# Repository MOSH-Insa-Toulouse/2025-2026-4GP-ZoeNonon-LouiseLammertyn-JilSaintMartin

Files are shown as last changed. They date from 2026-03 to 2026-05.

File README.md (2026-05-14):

# 2025-2026-4GP-ZoeNonon-LouiseLammertyn-JilSaintMartin
### Introduction

Dans le cadre de la formation en Génie Physique de l'INSA Toulouse, les étudiants de 4ème année doivent réaliser un capteur low-tech à base de graphite et en faire une analyse critique. Le but final étant de répondre à la question suivante:  

<p align="center">
  <strong>Un capteur graphite low-tech peut-il remplacer un flexeur commercial ?</strong>
</p>

Ce capteur graphitte se base sur les travaux de:

  - [1]	K.-H. Müller, J. Herrmann, B. Raguse, G. Baxter, and T. Reda, “Percolation model for electron conduction in films of metal nanoparticles linked by organic molecules,” Phys. Rev. B, vol. 66, no. 7, p. 075417, Aug. 2002, doi: 10.1103/PhysRevB.66.075417.
  
  - [2]	C.-W. Lin, Z. Zhao, J. Kim, and J. Huang, “Pencil Drawn Strain Gauges and Chemiresistors on Paper,” Sci. Rep., vol. 4, no. 1, p. 3812, Jan. 2014, doi: 10.1038/srep03812.
  
  - [3]	K.-H. Müller, J. Herrmann, G. Wei, B. Raguse, and L. Wieczorek, “Electron transport in nanoparticle assemblies,” in 2010 International Conference on Nanoscience and Nanotechnology, Feb. 2010, pp. 316–318. doi: 10.1109/ICONN.2010.6045236.

### Description du projet 
Le capteur de contrainte en graphite repose sur un réseau conducteur de particules de graphite déposées sur un substrat en papier.
Lorsque l'on trace un trait au crayon sur du papier, les particules de graphite adhèrent aux fibres, formant ainsi un mince film conducteur.
Ce film se comporte comme un système granulaire désordonné où la conduction électrique s'effectue par le biais des contacts entre les particules de graphite.
La déformation mécanique affecte ce réseau :
  - Sous contrainte de traction, la distance entre les particules augmente, ce qui réduit les contacts électriques et augmente la résistance.
  - Sous contrainte de compression, les particules sont rapprochées, ce qui améliore la connectivité et diminue la résistance.

La réponse du capteur est donc régie par les variations du réseau et les effets de tunnel entre particules voisines.
En raison de sa structure, le capteur est très sensible aux petites déformations, mais il est également influencé par des paramètres de fabrication tels que la densité du graphite, la dureté du crayon et les conditions environnementales (humidité, température).

<p align="center">
échelle_crayon
</p>
<p align="center">
  <em>Echelle évaluant la dureté de différentes mines de crayons</em>
</p>

**La variation de résistance qui en résulte peut être mesurée à l'aide d'un circuit à transimpédance, afin d'obtenir un signal analogique.**

Ce projet se divise en plusieurs étapes décrites ci-dessous. 

<p align="center">
Logo en noir
</p>
<p align="center">
  <em>Logo du capteur graphite "GraphiFlop"</em>
</p>

### Livrables
Pour valider ce projet nous devons proposer: 
- Un circuit imprimé (PCB) pour créer les circuits électroniques reliant nos composants
- Un code arduino qui permet de contrôler un ARDUINO afin de mesurer la résistance du capteur, faire nos tests et contrôler des éléments tels que le bluetooth, l'écran ou l'encodeur rotatoire
- Une datasheet présentant les caractéristiques du capteur graphite fabriqué
- Une application ANDROID permettant de recevoir les données par bluetooth et les afficher sur un graphique

### Matériel
Afin de réaliser ce capteur, nous utilisons le matériel suivant: 

- Une carte Arduino UNO
- Un écran OLED (I2C)
- Un potentiomètre numérique MCP41050
- Un encodeur rotatoire
- Un capteur de déformation en papier low tech
- Un module bluetooth

Pour réaliser l'amplificateur transimpédance, nous avons utilisé: 

- Un amplificateur opérationnel LTC1050
- Deux condensateurs de 100nF
- Un condensateur de 1µF
- Deux résistances de 100kΩ
- Deux résistances de 1kΩ
- Une résistance de 10kΩ

### LTspice
La première étape de se projet est de simuler le circuit d'amplification transimpédance du capteur sur LTspice. 
Le  montage est un amplificateur à transimpédance (TIA) basé sur l’AOP LTC1050.

Le principe du montage est de convertir le courant traversant le capteur en une tension exploitable. L’amplificateur opérationnel, configuré en transimpédance, permet d’obtenir une tension de sortie proportionnelle à la valeur de la résistance.

Un filtre passe-bas est ajouté en sortie afin de réduire le bruit et de fournir un signal stable, compatible avec une entrée analogique.

Dans la suite du projet, R2 sera remplacée par un potentiomètre numérique, afin de permettre la calibration de l’Arduino sur une plage de tension comprise entre 0 et 5 V.

<p align="center">
capteur
</p>
<p align="center">
  <em>Circuit d'amplification transimpédance sur LTspice</em>
</p>

Pour consulter les différents fichiers, aller à [2.LTSpice](https://github.com/MOSH-Insa-Toulouse/2025-2026-4GP-ZoeNonon-LouiseLammertyn-JilSaintMartin/tree/main/2.LTSpice)

### Kicad

Une fois la simulation validée sur LTspice, l'étape suivante consiste à transformer le schéma théorique en un objet physique fonctionnel : le Circuit Imprimé (PCB). 
Pour ce faire, nous utilisons la suite logicielle KiCad.

Cette phase de conception se décompose en trois étapes majeures :

**Saisie schématique et empreinte**

La première étape consiste à reproduire le circuit de l’amplificateur transimpédance.
- Intégration des composants: Nous y plaçons l'AOP LTC1050, les composants passifs (résistances, condensateurs) et les connecteurs nécessaires à l'Arduino Uno, l'écran OLED et l'encodeur rotatif.
- Association des empreintes: Chaque symbole schématique est lié à une empreinte physique réelle. Cette étape est cruciale pour assurer que les composants pourront être soudés correctement sur le cricuit final.

<p align="center">
 shm
</p>
<p align="center">
  <em>Visualisation de la schématique du montage sur KiCad</em>
</p>

**Routage et placement**

Le passage au routage permet de définir la disposition physique des éléments sur la carte de cuivre.
- Placement des composants et routages: Nous avons disposé les composants afin de pouvoir router par la suite le plus efficacement possible, sans que les composants et les pistes ne se superposent.
- Plan de masse: Un plan de masse a été intégré pour stabiliser les potentiels et réduire le bruit sur le circuit analogique.

<p align="center">
pcb  
</p>
<p align="center">
  <em>Visualisation du routage du montage sur KiCad</em>
</p>

**Visualisation 3D et vérification**

Enfin, KiCad permet une modélisation 3D du projet. Cet outil nous a permis de:
- Vérifier l'encombrement mécanique des composants.
- Valider la cohérence globale avant la fabrication du PCB.

<p align="center">
  
</p>
<p align="center">
  <em>Visualisation 3D du montage global sur KiCad</em>
</p>

Pour consulter les différents fichiers, aller à [3.KiCad](https://github.com/MOSH-Insa-Toulouse/2025-2026-4GP-ZoeNonon-LouiseLammertyn-JilSaintMartin/tree/main/3.KiCad)

### Fabrication PCB et soudage

<p align="center">
  
</p>
<p align="center">
  <em>Fichier généré par KiCad pour l'impression du PCB</em>
</p>

Une fois le routage validé sous KiCad et le fichier de perçage généré, nous avons pu imprimer notre circuit électronique (merci Cathy <3). Ensuite, nous avons percé et soudé le montage complet. Avant de passer au code Arduino, nous avons vérifié que tout fonctionnait bien à l'aide d'un multimètre, en effectuant les étapes suivantes:
- Vérification que chaque piste relie bien les bons points du schéma.
- Absence totale de court-circuit entre le 5V et le GND.

<p align="center">
  Face_arrière_PCB
</p>
<p align="center">
  <em>Face arrière du PCB</em>
</p>

### Arduino
Il a ensuite été nécessaire de réaliser un code arduino afin de pouvoir contrôler la carte. Ce code permet notamment d'effectuer les mesures sur le capteur graphite et de contrôler les différents composants tels que le module bluetooth, l'écran OLED et l'encodeur rotatoire. 

**Mesure**

La première partie du code est dédiée à la mesure de la tension aux bornes du capteur. A l'aide d'une fonction, la tension mesurée permet de déduire la résistance du capteur. 

Une fonction de calibration a aussi été créee afin de calibrer la tension aux bornes du capteur. Comme l'arduino UNO permet de délivrer une tension entre 0V et 5V, il est intéressant de régler le potentiomètre numérique afin que la tension aux bornes du capteur lorsque le capteur n'est pas tordu, soit de 2,5V. Ce potentiomètre numérique remplace dans le montage électronique la résistance R2.

Notre montage permet aussi d'utiliser un flexor commercial. Pour cela, une fonction au sein du code permet de mesurer la tension différement et d'en déduire la résistance. La calibration n'est cependant pas nécessaire sur ce capteur. 

<p align="center">
  Flexor
</p>
<p align="center">
  <em>Flexor commercial</em>
</p>

La lecture de tension aux bornes du capteur graphite ou du flexor commercial s'effectue toutes les 100ms. 

**Composants pour l'utilisateur**
<p align="center">
  Schéma_composants
</p>
<p align="center">
  <em>Schéma des différents composants</em>
</p>

Le reste du code permet de gérer le reste des composants. Une fonction permet de gérer l'affichage sur l'écran OLED. Sur cet écran, l'affichage d'un menu permet d'intéragir avec l'utilisateur. Une fonction gère l'encodeur rotatoire qui permet à l'utilisateur de se déplacer sur le menu. Enfin, une dernière fonction permet d'envoyer les données mesurées à l'aide du module bluetooth sur un téléphone connecté. 

<p align="center">
  Menu
</p>
<p align="center">
  <em>Menu affiché sur l'écran OLED</em>
</p>

Pour consulter les différents fichiers, aller à [4.Arduino](https://github.com/MOSH-Insa-Toulouse/2025-2026-4GP-ZoeNonon-LouiseLammertyn-JilSaintMartin/tree/main/4.Arduino)

### Application
A l'aide du site internet "MIT App Inventor", nous avons pu créer une interface pour téléphone ANDROID sur laquelle l'arduino UNO peut communiquer des données par bluetooth. Le code de cette application se base sur l'empilage de blocs de code. 

Le code traite d'abord la communication avec le module bluetooth de l'arduino en s'assurant que les données reçues sont bien des valeurs numériques positives. Une fois les données réceptionnées, les données sont affichées sur un graphique qui se met à jour en continu. 

L'application permet par ailleurs d'afficher le mode de mesure en cours (mesure de tension ou de résistance) ainsi que le capteur utilisé. 

<p align="center">
  interface_app
</p>
<p align="center">
  <em>Interface de l'application GraphiFlop</em>
</p>

Pour consulter les différents fichiers, aller à [5.Application](https://github.com/MOSH-Insa-Toulouse/2025-2026-4GP-ZoeNonon-LouiseLammertyn-JilSaintMartin/tree/main/5.Application)

### Banc de tests
Pour cette partie, nous avons utilisé un banc de test conçu par les groupes précédents.
<p align="center">
  banc_test_sans_fond
</p>
<p align="center">
  <em>Banc de test</em>
</p>

Afin de vérifier les résultats obtenus, nous avons tracé la variation relative de la résistance du capteur en fonction de la déformation mécanique. La résistance relative est mesurée pour chaque courbure du banc de test.
La déformation peut être calculée à partir de la géométrie du dispositif selon la relation suivante :

<p align="center">
deformation
</p>

Ensuite, à l’aide du code arduino, nous avons mesuré la résistance du capteur pour quatre types de crayons différents. Une mesure de référence à plat a d’abord été réalisée, puis des mesures ont été effectuées pour différentes courbures du banc de test, en compression et en tension.
La résistance relative est définie par :

 <p align="center">
Rrelative
</p>

Pour consulter les différents fichiers, aller à [6.Banc de tests](https://github.com/MOSH-Insa-Toulouse/2025-2026-4GP-ZoeNonon-LouiseLammertyn-JilSaintMartin/tree/main/6.Banc%20de%20tests)
### Résulats
Nous avons obtenu les courbes suivantes :

<p align="center">
Résultat_compression 
resultat_flexion
</p>

On observe que les résultats obtenus en flexion présentent une relation globalement linéaire entre la déformation et la variation de résistance. Le capteur est donc particulièrement adapté à la mesure de flexion. Cependant la durée de vie du capteur est courte les valeurs sont tres vraibale lorsque que celui ci a deja été pliée. 
On retrouve bien les résultats attendus concernant la sensibilité du capteur en fonction du grade du crayon. Les crayons "tendres" (ex : 6B, à forte concentration en graphite) présentent une sensibilité plus faible que les crayons plus "durs" (ex : HB). 

Cela s’explique par la structure du réseau conducteur : une plus forte densité de graphite rend le chemin de conduction plus stable, ce qui réduit l’amplitude relative des variations de résistance lors des déformations.
En revanche, les résultats en compression sont moins concluants. Bien que les courbes restent globalement affines, la variation de résistance n’est pas entièrement exploitable : le signal tend à revenir vers la résistance au repos lorsque le capteur est courbé.

Ce comportement peut s’expliquer par un phénomène mécanique : en compression, la couche de graphite entre en contact avec le banc de test, entraînant une perte de matière  et une modification irréversible du réseau conducteur.

Enfin, nous n’avons pas réussi à obtenir de mesures exploitables avec les crayons H et 2H, car le signal électrique généré était trop faible pour être détecté par le système de mesure.

Pour consulter les différents fichiers, aller à [7.Datasheet](https://github.com/MOSH-Insa-Toulouse/2025-2026-4GP-ZoeNonon-LouiseLammertyn-JilSaintMartin/tree/main/7.Datasheet)

### Erreur rencontré
Au cours de ce projet, de nombreuse erreurs ont été rencontrées, que nous détaillons ci-dessous. 

Les premiers problèmes rencontrés sont liés à une erreur de routage sur KiCad. En effet, nous avons vite remarqué que certains composants n'étaient pas reliés au bonnes pins de l'arduino comme par exemple le potentiomètre numérique. Nous avons aussi oublié d'ajouter sur le PCB initial des broches afin de connecter le flexor commercial ou bien une capacité associée à l'encodeur rotatoire. Nous avons cependant pu remédier à ces erreurs en ressoudant avec des fils certaines pistes du PCB (encore merci Cathy :)).

<p align="center">
  Face_arrière_PCB_avec_fils_sans_fond
</p>
<p align="center">
  <em>Face arrière du PCB (après réparation)</em>
</p>

Nous avons aussi rencontré des problèmes quant aux codes écrits lors de ce projet. En effet, nous avons fait face à des problèmes de RAM de l'écran OLED. Nous avons pu cependant régler ce problème. Par ailleurs, nous avons aussi eu des difficultés face à la fonction de calibration qui ne fonctionne pas toujours ou bien face à certaines boucles de l'application ANDROID qui ne sont pas toujours lues. Nous n'avons malheureusement pas pu remédier à ces problèmes. 

Enfin, nous avons rencontré des difficultés quant au capteur en lui-même. Le capteur graphite a, comme expliqué précédemment, une durée de vie assez courte ce qui rend difficile certaines mesures.

### Conclusion
Ce capteur est fiable comme le montre les courbes réalisées. Il permet d'effectuer des mesurer tant en flexion qu'en compression (ce qui n'est pas le cas pour un flexor commercial) avec une sensibilité certaine. 
Un avantage considérable du capteur graphite est son prix très bas en comparaison d'un capteur commercial. 

Cependant, la durée de vie du capteur est courte ce qui le rend peut réutilisable. 

Pour conclure, ce capteur graphite est commercialisable à condition de pouvoir augmenter sa durée de vie. On pourrait par exemple proposer l'ajout d'une couche de protection sur le capteur afin d'éviter d'enlever du graphite ainsi que d'utiliser un papier moins fragile. 

<p align="center">
  <strong>GraphiFlop c'est validé! 😎👍</strong>
</p>

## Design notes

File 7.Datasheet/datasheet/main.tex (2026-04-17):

\documentclass[a4paper,12pt,oneside,pdflatex,italian,final,twocolumn]{article}

\usepackage[utf8]{inputenc}
\usepackage{parallel}
\usepackage{siunitx}
\usepackage{booktabs}
\usepackage{fancyhdr}

\usepackage[export]{adjustbox}
\usepackage[margin=0.5in]{geometry}
\addtolength{\topmargin}{0in}

\usepackage{libertine}
\renewcommand*\familydefault{\sfdefault}  %% Only if the base font of the document is to be sans serif
\usepackage[T1]{fontenc}

\title{Graphiflop00001}
\author{Nonon Zoé, Lammertyn Louise, Saint-Martin Jil }
\date{April 2019}

\begin{document}

\pagestyle{fancy}

\lhead{insa toulouse}
\chead {\today}
\rhead{Projet capteur}

\onecolumn

\begin{figure}
\begin{minipage}{0.47\textwidth}
\centering
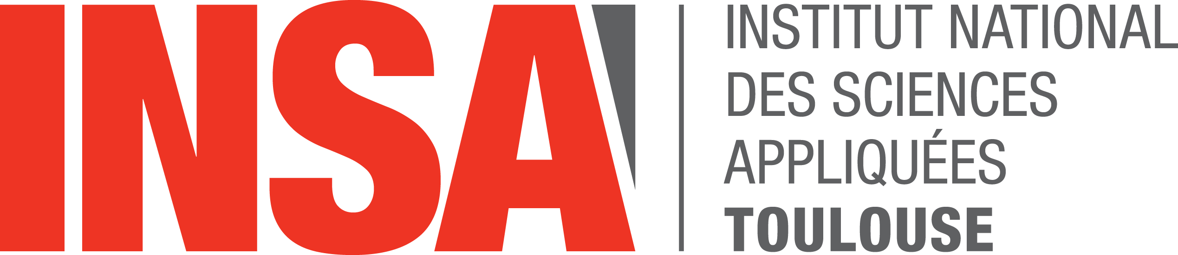
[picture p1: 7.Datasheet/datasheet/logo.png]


\end{minipage}
\hfill
\begin{minipage}{0.47\textwidth}
\raggedleft
\Huge \textbf{Graphiflop00001}
\end{minipage}
\end{figure}

\begin{figure}
\begin{minipage}{0.47\textwidth}
\section{Overview}
\begin{itemize}
    \item Paper-based graphite strain sensor
    \item Analog response based on resistance variation
    \item Sensitive to tensile and compressive deformation
    \item Low-cost and easy fabrication (pencil deposition)
    \item Compatible with 0--5V measurement circuits
    \item Flexible and lightweight structure
\end{itemize}

\end{minipage}
\hfill
\begin{minipage}{0.47\textwidth}
\centering
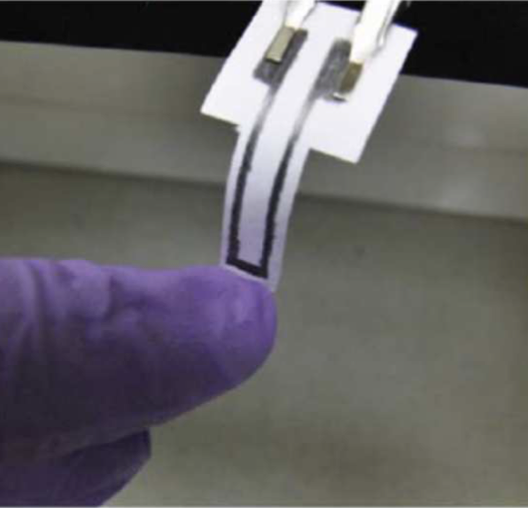
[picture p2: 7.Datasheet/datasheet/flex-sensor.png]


\end{minipage}
\end{figure}

\section{Description}

The Graphite Strain Sensor is based on a conductive network of graphite particles deposited on a paper substrate.

When a pencil trace is drawn on paper, graphite particles adhere to the fibers, forming a thin conductive film.
 This film behaves as a disordered granular system where electrical conduction occurs through contacts between graphite particles.

Mechanical deformation affects this network:
\begin{itemize}
    \item Under tensile strain, the distance between particles increases, reducing electrical contacts and increasing resistance.
    \item Under compressive strain, particles are pushed closer together, improving connectivity and decreasing resistance.
\end{itemize}

The sensor response is therefore governed by variations in the percolation network and tunneling effects between neighboring particles.

Due to its structure, the sensor is highly sensitive to small deformations but also influenced by fabrication parameters such as graphite density,
 pencil grade, and environmental conditions (humidity, temperature).

The resulting resistance variation can be measured using a transimpedance circuit, to obtain a usable analog signal.

\section{Technical specification}

\centering
\begin{tabular}{lcccc}
\toprule
Parameter & Min & Typical & Max & Unit \\
\midrule
Supply voltage & -- & 5 & - & V \\
Output voltage & 0 & -- & 5 & V \\
Output current & -- & $10^{-7}$ & -- & A \\
Operating temperature & 10 & 20 & 35 & °C \\
Humidity (operating) & 0 & 30 & 60 & \% \\
Sensor resistance & $10^5$ & $10^6$ & $10^7$ & $\Omega$ \\
Paper Thickness & 15& -- & 35 & mm \\
Number of pins & \multicolumn{3}{c}{2} & -- \\
\bottomrule

\end{tabular}
\begin{tabular}{lcccc}
\toprule
Pad & name & Value &\\
\midrule
Pad 1 & Vin & VCC  \\
Pad 2 & Out  & Analog output \\
\bottomrule
\end{tabular}

\raggedright

\section{Pin Configuration}

\begin{center}
\begin{tabular}{lll}
\toprule
Pin Arduino & Signal & Description \\
\midrule
5V & VCC & Power supply to sensor and circuit \\
GND & GND & Common ground \\

A0 & AO & Amplified analog output \\
A1 & FLEX & Flex sensor input \\

D8 & CS & Digital Potentiometer \\
D11 & MOSI & Digital Potentiometer  \\
D13 & SCK &  Clock \\

A4 & SDA & I2C Data (OLED display) \\
A5 & SCL & I2C Clock (OLED display) \\

D2 & CLK & Encoder clock signal \\
D4 & DATA & Encoder data signal \\
D5 & SW & Encoder push button \\

D10 & TX & Bluetooth transmission \\
D9 & RX & Bluetooth reception \\

\bottomrule
\end{tabular}
\end{center}

\section{Kicad (Scheme and  PCB)}
\begin{figure}[h]
    \centering
    \begin{minipage}{0.48\textwidth}
        \centering
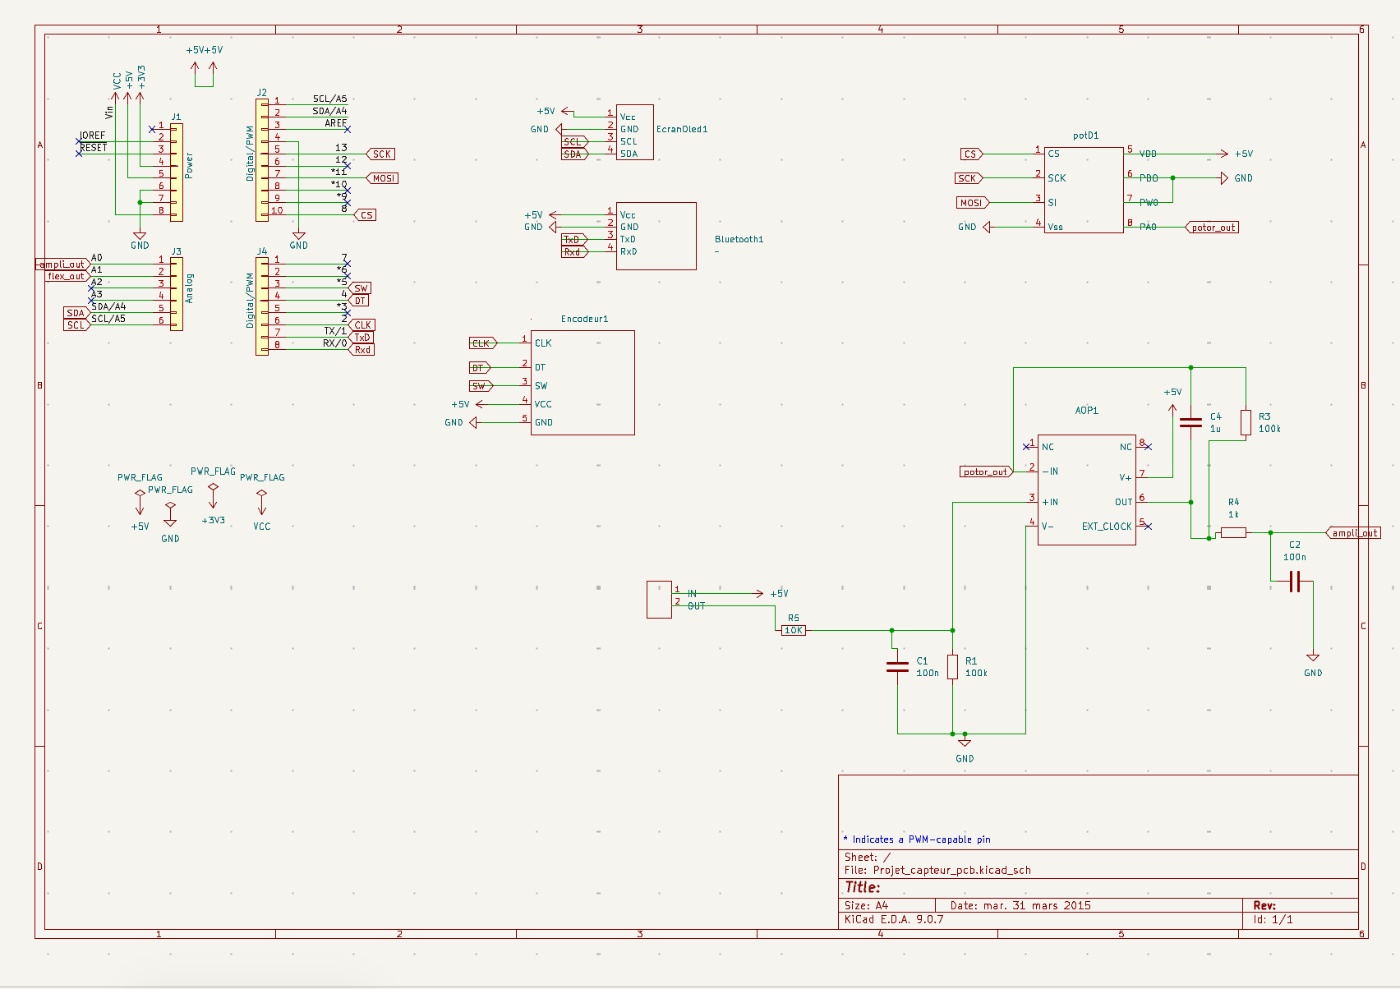
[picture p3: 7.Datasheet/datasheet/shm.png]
        
        \caption{Electrical diagram}
    \end{minipage}
    \hfill
    \begin{minipage}{0.48\textwidth}
        \centering
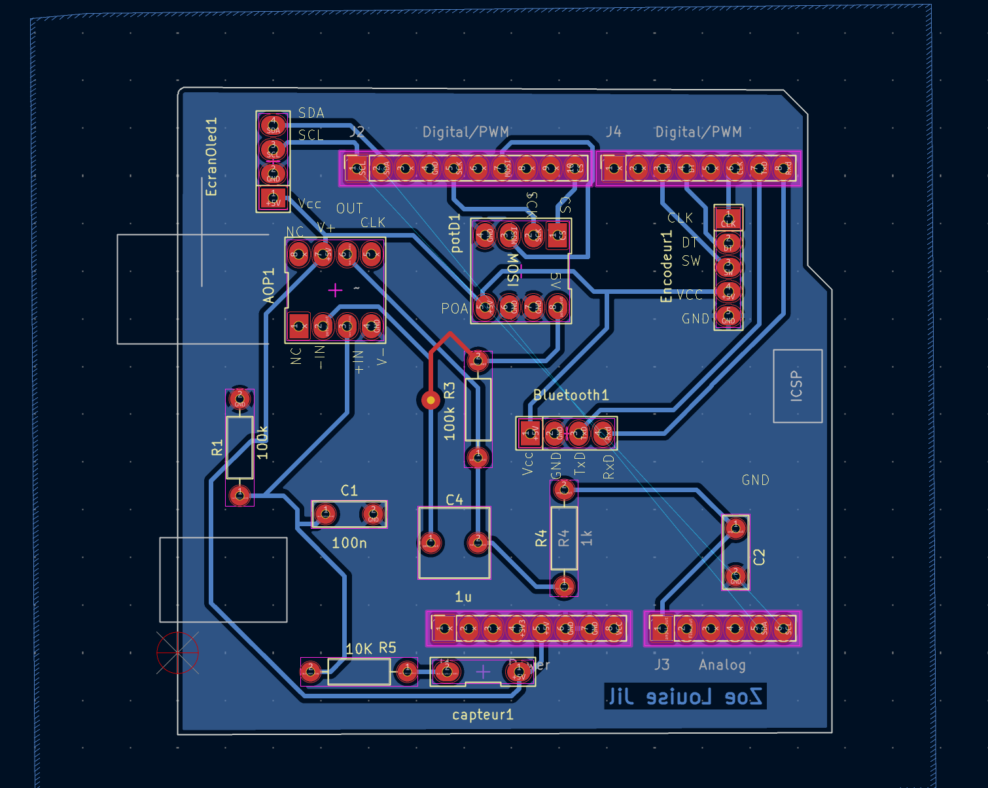
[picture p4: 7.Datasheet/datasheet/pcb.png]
        
        \caption{PCB routing}
    \end{minipage}
\end{figure}

\section{Low tech Captor}
\begin{center}
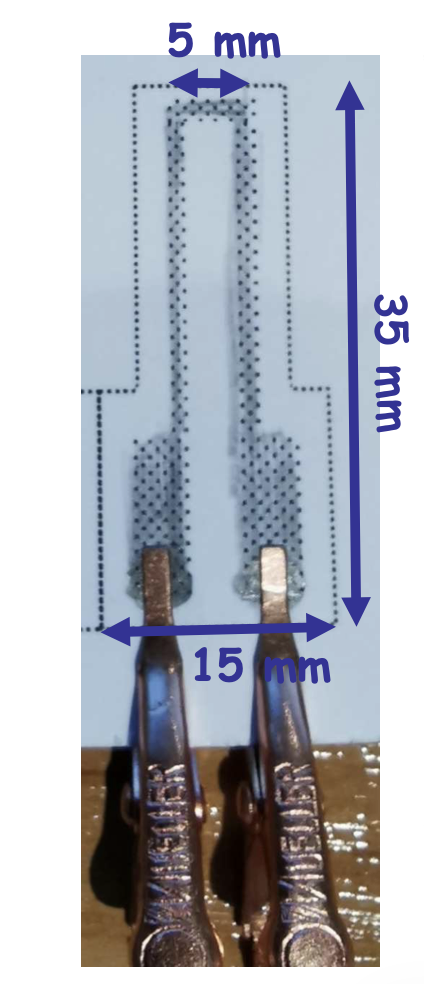
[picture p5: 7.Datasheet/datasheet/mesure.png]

\end{center}

\section{Typical Value}

\centering
\begin{tabular}{lc}
\toprule
Pencil Grade & Flat Resistance \\
\midrule
2B & \SI{1.93e6}{\ohm} \\
HB & \SI{4.08e6}{\ohm} \\
4B & \SI{5.69e5}{\ohm} \\
B  & \SI{1.80e6}{\ohm} \\
\bottomrule
\end{tabular}

\raggedright
\begin{figure}[h]
\centering

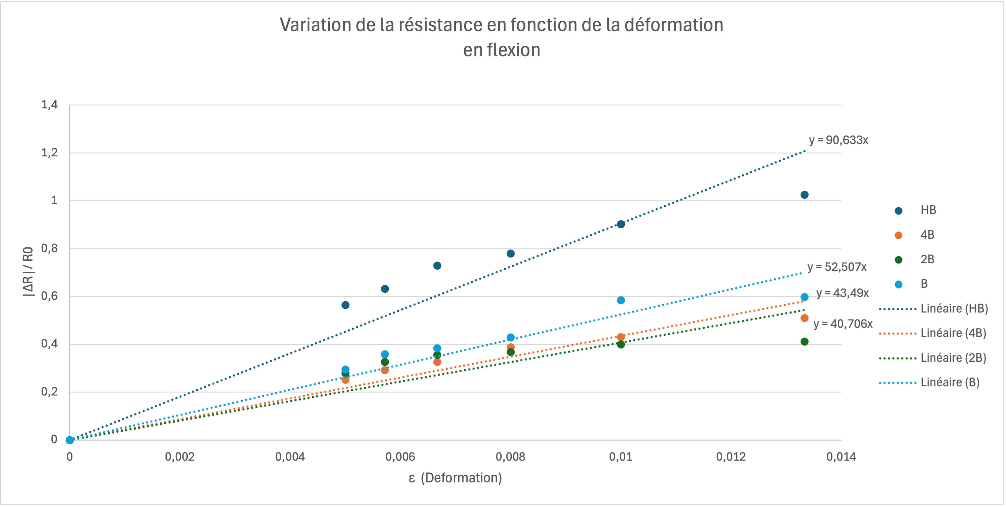
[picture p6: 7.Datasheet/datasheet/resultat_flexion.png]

\caption{Bending result}

\vspace{0.5cm}

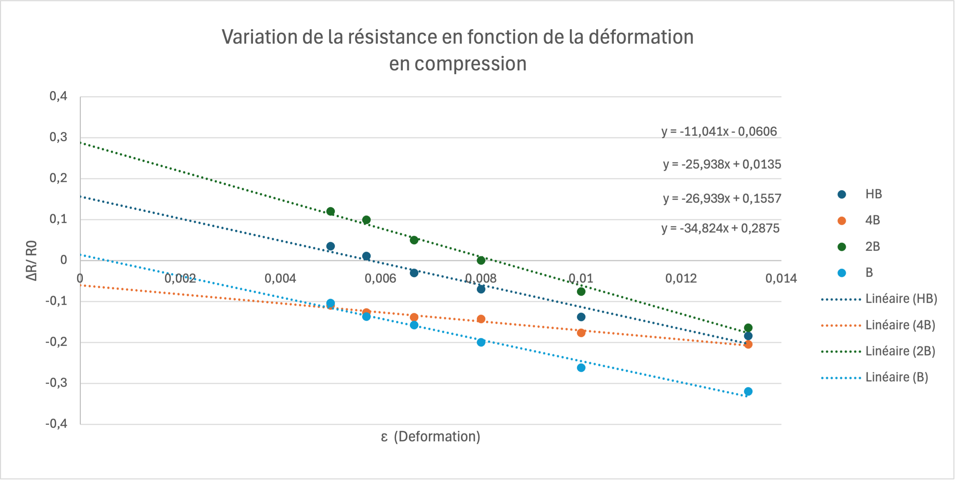
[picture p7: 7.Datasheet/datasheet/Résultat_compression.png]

\caption{Compression result}

\end{figure}
\end{document}

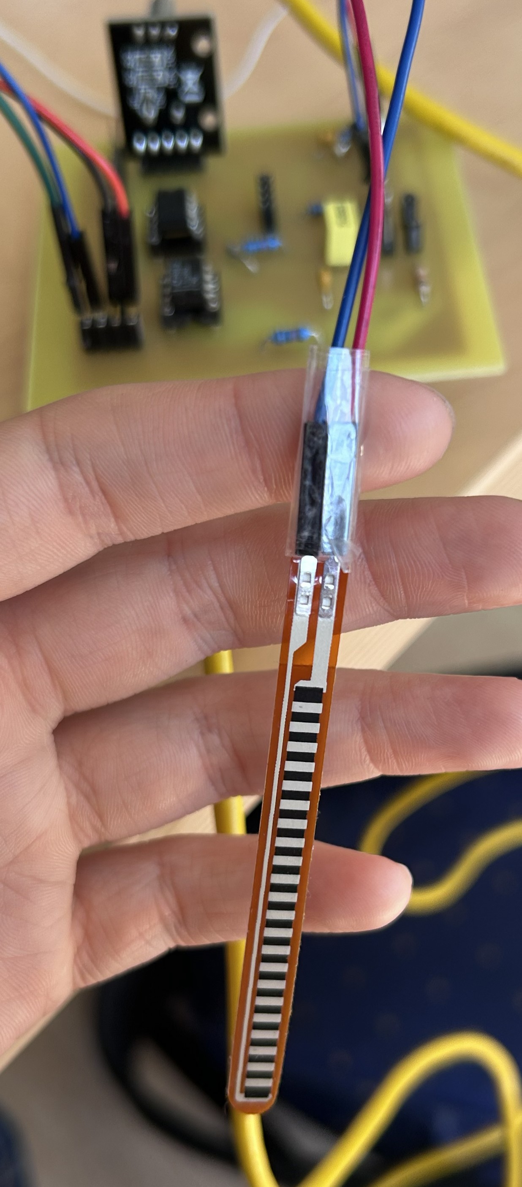
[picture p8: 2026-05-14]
1.Photos/Flexor_commercial.jpg

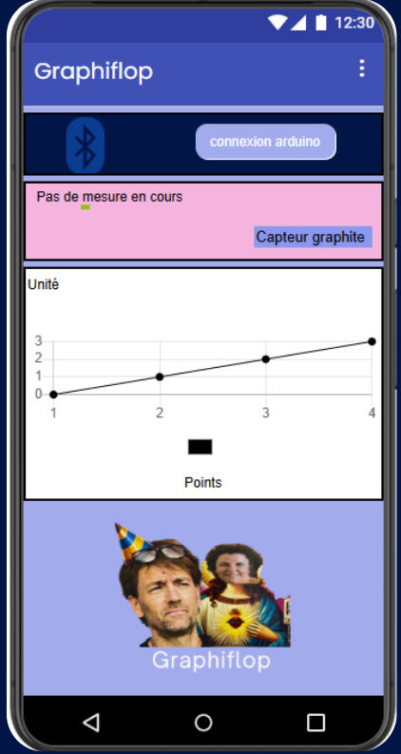
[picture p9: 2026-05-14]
1.Photos/Interface_application.png

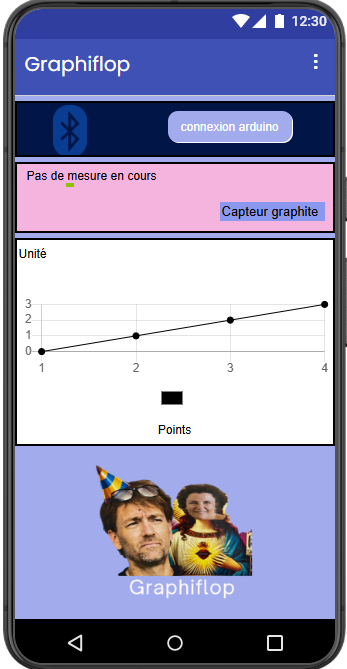
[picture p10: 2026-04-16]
5.Application/Interface_app.png

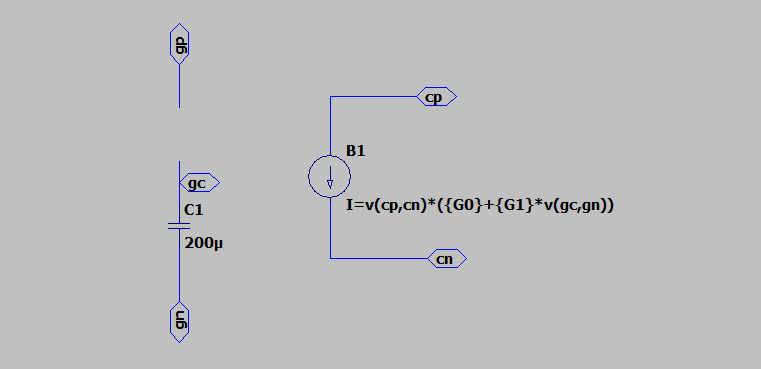
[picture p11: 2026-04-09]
2.LTSpice/catpeur2.png

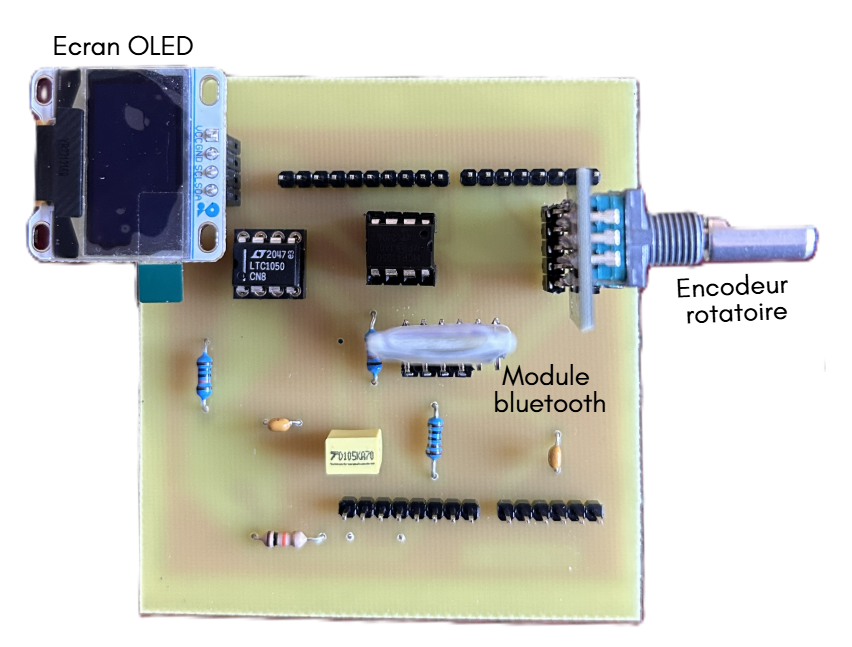
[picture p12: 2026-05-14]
1.Photos/Carte_du_capteur.png

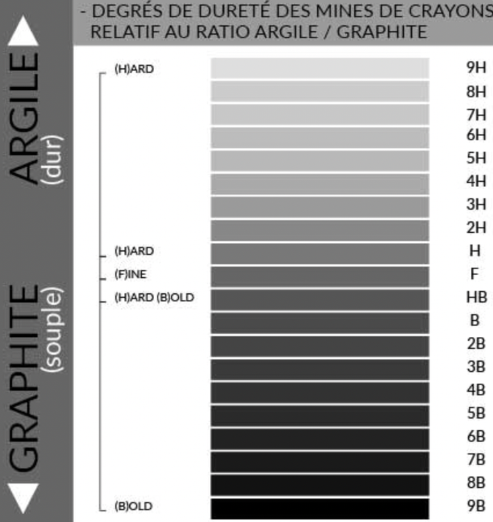
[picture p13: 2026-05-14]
1.Photos/Echelle_dureté_crayons.png

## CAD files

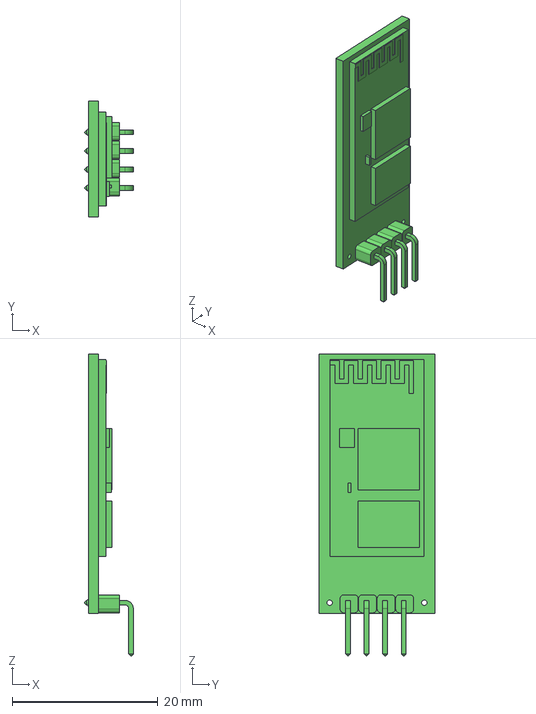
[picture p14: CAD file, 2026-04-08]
3.KiCad/Projet_capteur_pcb/Model 3d/hc-05-bluetooth-module-4/HC-05 Bluetooth Module.stp
6.68 x 16.0 x 41.4 mm

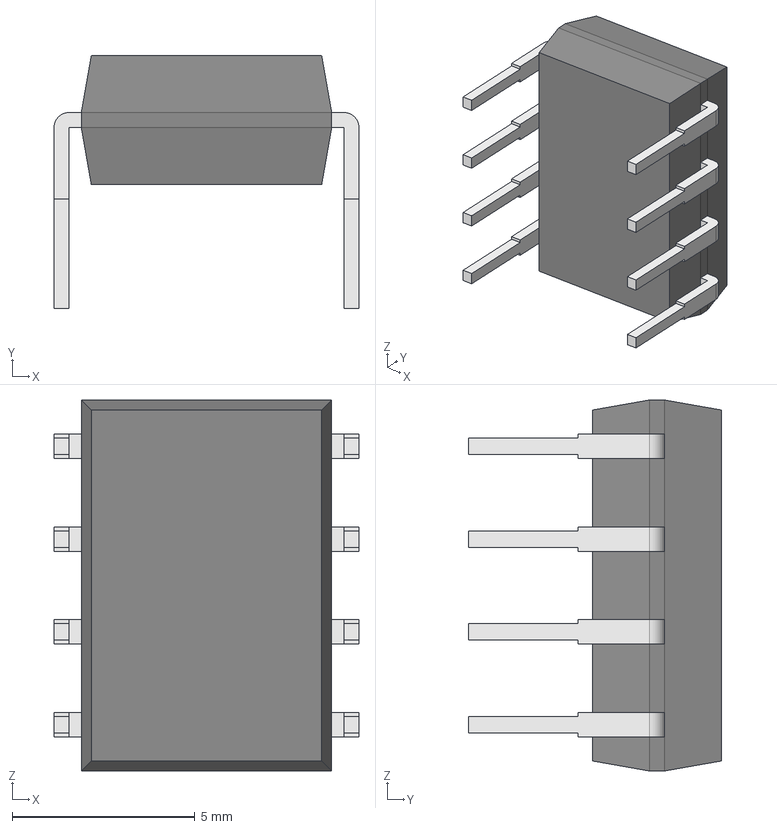
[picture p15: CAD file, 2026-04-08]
3.KiCad/Projet_capteur_pcb/Model 3d/LTC1050CN8/LTC1050CN8.step
8.35 x 6.93 x 10.2 mm
Body001 (Mirror #1) x 5

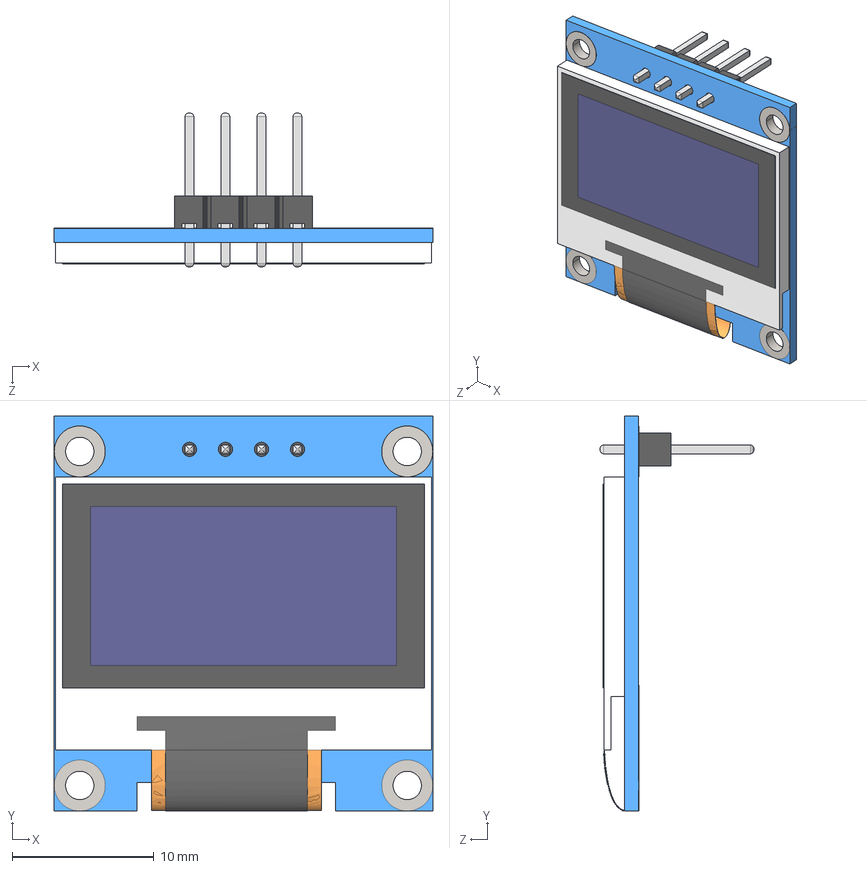
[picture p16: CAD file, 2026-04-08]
3.KiCad/Projet_capteur_pcb/Model 3d/OLED 128x64.STP
26.7 x 27.9 x 10.8 mm

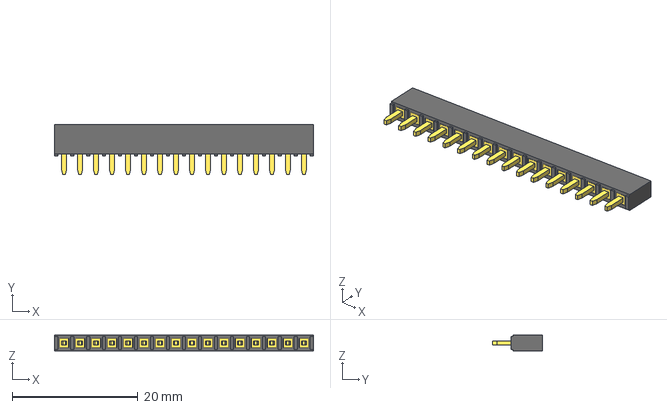
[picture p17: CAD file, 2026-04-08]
3.KiCad/Projet_capteur_pcb/Model 3d/pin-header-female-2-54mm-different-pin-numbers-1/16-Pin Header - Female - 2.54mm.step
41.1 x 8.00 x 2.50 mm

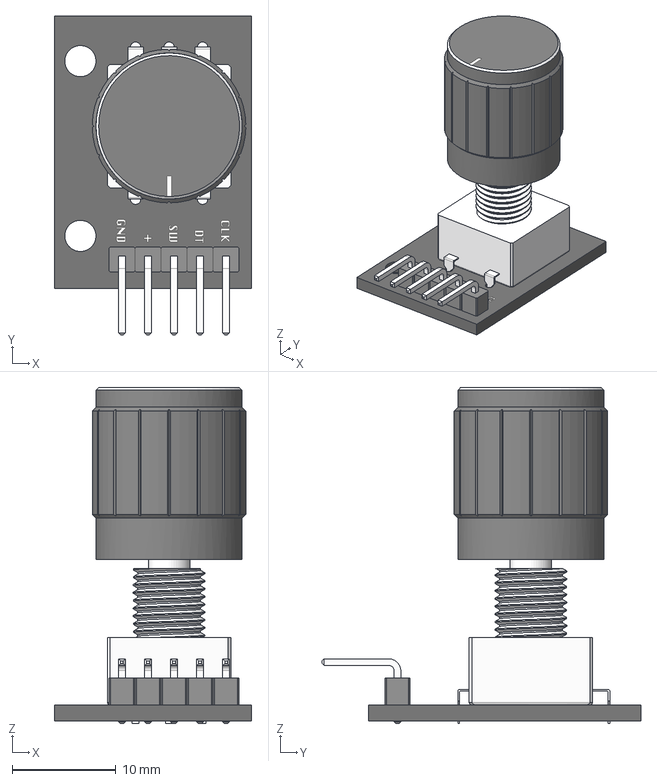
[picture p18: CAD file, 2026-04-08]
3.KiCad/Projet_capteur_pcb/Model 3d/rotary-encoder-ky-040-2/Rotary Encoder - KY-040.step
19.0 x 30.8 x 32.4 mm

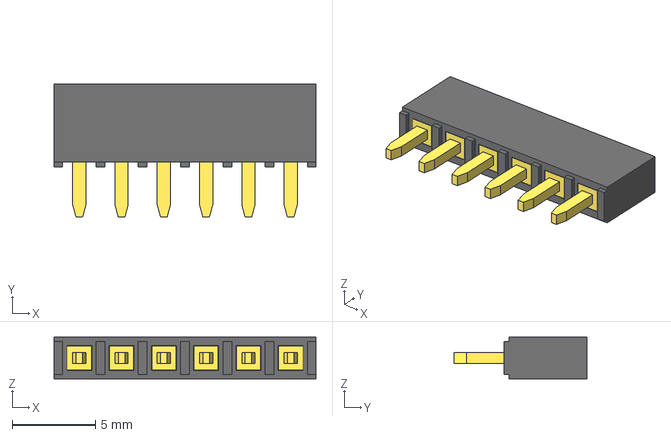
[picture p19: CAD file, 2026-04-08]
3.KiCad/Projet_capteur_pcb/Model 3d/pin-header-female-2-54mm-different-pin-numbers-1/6-Pin Header - Female - 2.54mm.step
15.7 x 8.00 x 2.50 mm

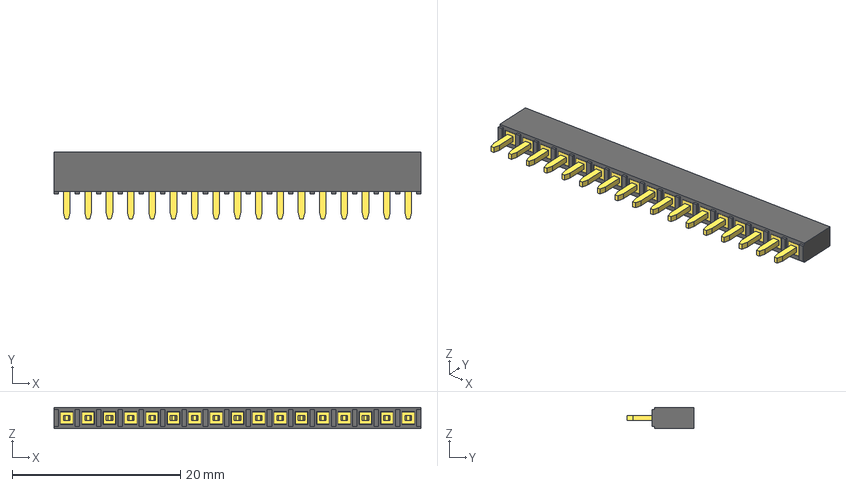
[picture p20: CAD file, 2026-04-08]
3.KiCad/Projet_capteur_pcb/Model 3d/pin-header-female-2-54mm-different-pin-numbers-1/17-Pin Header - Female - 2.54mm.step
43.7 x 8.00 x 2.50 mm

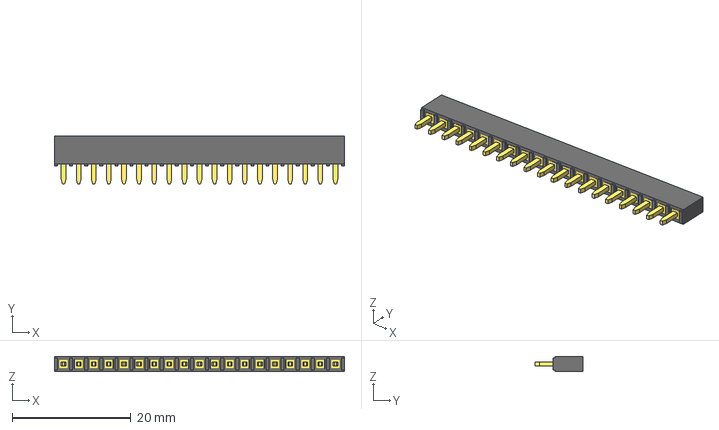
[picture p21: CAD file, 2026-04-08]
3.KiCad/Projet_capteur_pcb/Model 3d/pin-header-female-2-54mm-different-pin-numbers-1/19-Pin Header - Female - 2.54mm.step
48.8 x 8.00 x 2.50 mm

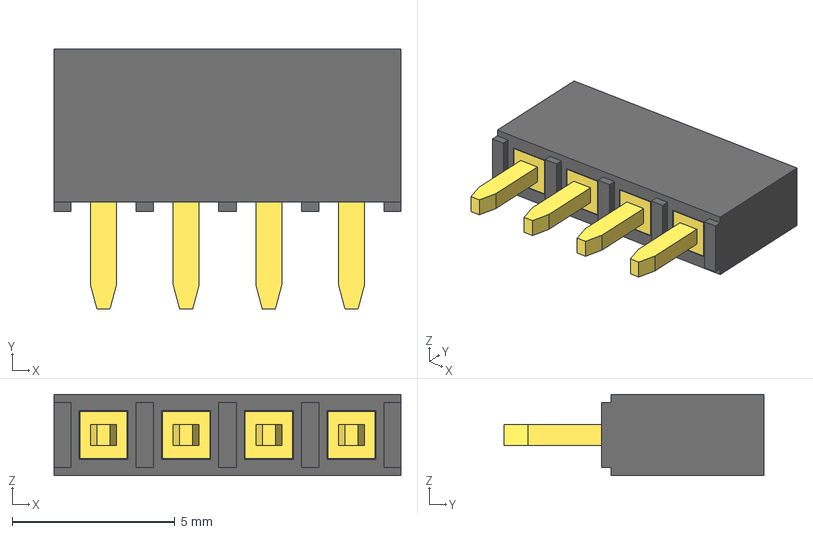
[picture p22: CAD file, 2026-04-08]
3.KiCad/Projet_capteur_pcb/Model 3d/pin-header-female-2-54mm-different-pin-numbers-1/4-Pin Header - Female - 2.54mm.step
10.7 x 8.00 x 2.50 mm

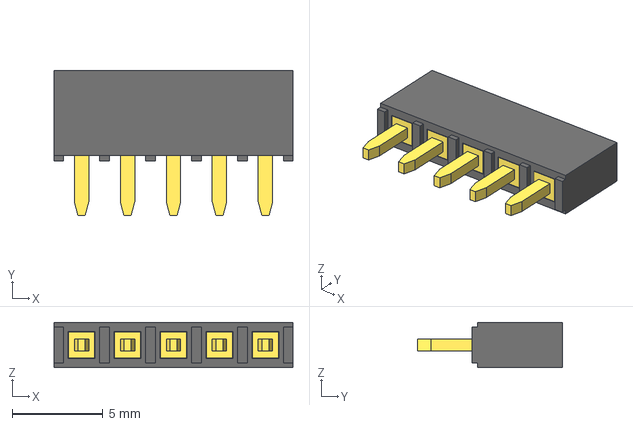
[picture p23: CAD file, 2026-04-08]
3.KiCad/Projet_capteur_pcb/Model 3d/pin-header-female-2-54mm-different-pin-numbers-1/5-Pin Header - Female - 2.54mm.step
13.2 x 8.00 x 2.50 mm

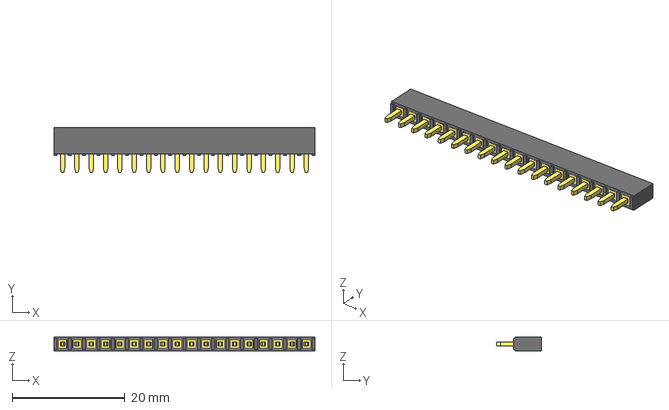
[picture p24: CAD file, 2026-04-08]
3.KiCad/Projet_capteur_pcb/Model 3d/pin-header-female-2-54mm-different-pin-numbers-1/18-Pin Header - Female - 2.54mm.step
46.2 x 8.00 x 2.50 mm

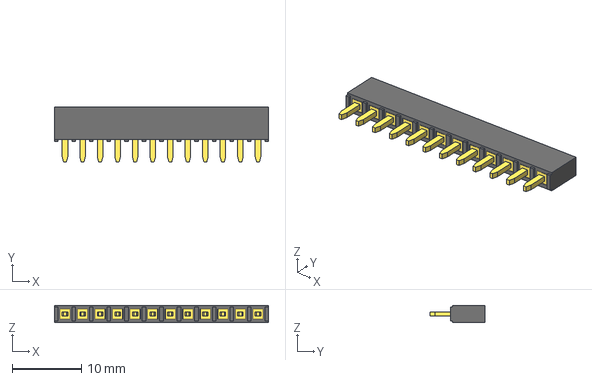
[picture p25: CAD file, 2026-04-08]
3.KiCad/Projet_capteur_pcb/Model 3d/pin-header-female-2-54mm-different-pin-numbers-1/12-Pin Header - Female - 2.54mm.step
31.0 x 8.00 x 2.50 mm

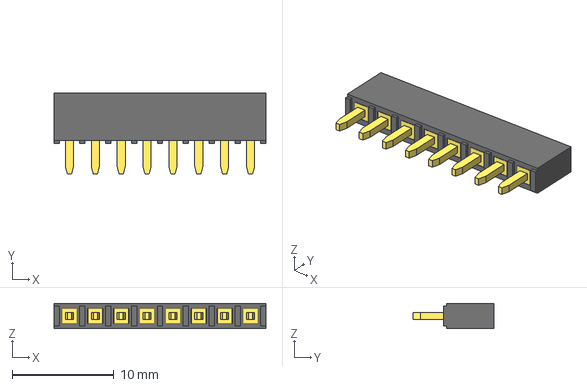
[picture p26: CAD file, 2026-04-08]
3.KiCad/Projet_capteur_pcb/Model 3d/pin-header-female-2-54mm-different-pin-numbers-1/8-Pin Header - Female - 2.54mm.step
20.8 x 8.00 x 2.50 mm

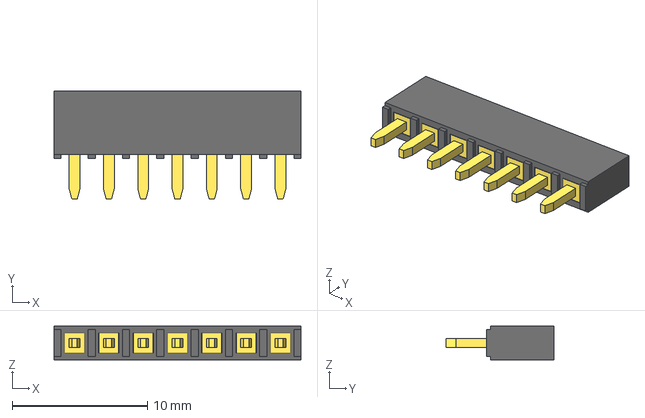
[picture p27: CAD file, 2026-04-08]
3.KiCad/Projet_capteur_pcb/Model 3d/pin-header-female-2-54mm-different-pin-numbers-1/7-Pin Header - Female - 2.54mm.step
18.3 x 8.00 x 2.50 mm

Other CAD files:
3.KiCad/Projet_capteur_pcb/Model 3d/pin-header-female-2-54mm-different-pin-numbers-1/11-Pin Header - Female - 2.54mm.step
3.KiCad/Projet_capteur_pcb/Model 3d/pin-header-female-2-54mm-different-pin-numbers-1/10-Pin Header - Female - 2.54mm.step
3.KiCad/Projet_capteur_pcb/Model 3d/pin-header-female-2-54mm-different-pin-numbers-1/9-Pin Header - Female - 2.54mm.step
3.KiCad/Projet_capteur_pcb/Model 3d/pin-header-female-2-54mm-different-pin-numbers-1/14-Pin Header - Female - 2.54mm.step
3.KiCad/Projet_capteur_pcb/Model 3d/MCP41010-E_P/MCP41010-E_P.step
3.KiCad/Projet_capteur_pcb/Model 3d/pin-header-female-2-54mm-different-pin-numbers-1/13-Pin Header - Female - 2.54mm.step
3.KiCad/Projet_capteur_pcb/Model 3d/pin-header-female-2-54mm-different-pin-numbers-1/15-Pin Header - Female - 2.54mm.step
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

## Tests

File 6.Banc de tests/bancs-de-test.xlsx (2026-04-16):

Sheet: compression
 |  |  |  |  | Test compression
e | Banc de test |  |  | type crayon |  | Type crayon | 4B |  |  | 2B |  |  | B |  |  | HB
0.2 | dcourbure | ecourbure | Epsilon |  |  |  | R0 | R | |ΔR|/ R0 | R0 | R | |ΔR|/ R0 | R0 | R | |ΔR|/ R0 | R0 | R | |ΔR|/ R0
 |  |  | 0 |  |  |  | 388163
 | 15 | 7.5 | 0.01333333333 |  |  | resitance | 388163 | 308649 | -0.2048469329 | 1674034 | 1399097 | -0.1642362103 | 2807866 | 1908847 | -0.3201787407 | 2645191 | 2157102 | -0.1845193788
 | 20 | 10 | 0.01 |  |  |  |  | 319383 | -0.1771936017 |  | 1546602 | -0.07612270719 |  | 2070945 | -0.2624487778 |  | 2279755 | -0.1381510825
 | 25 | 12.5 | 0.008 |  |  |  |  | 332474 | -0.1434680791 |  | 1674034 | 0 |  | 2246384 | -0.1999675198 |  | 2459099 | -0.0703510635
 | 30 | 15 | 0.006666666667 |  |  |  |  | 334280 | -0.1388153946 |  | 1757188 | 0.04967282624 |  | 2363422 | -0.1582853313 |  | 2564472 | -0.03051537677
 | 35 | 17.5 | 0.005714285714 |  |  |  |  | 338861 | -0.1270136515 |  | 1839807 | 0.09902606518 |  | 2422114 | -0.1373826244 |  | 2673191 | 0.01058524696
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

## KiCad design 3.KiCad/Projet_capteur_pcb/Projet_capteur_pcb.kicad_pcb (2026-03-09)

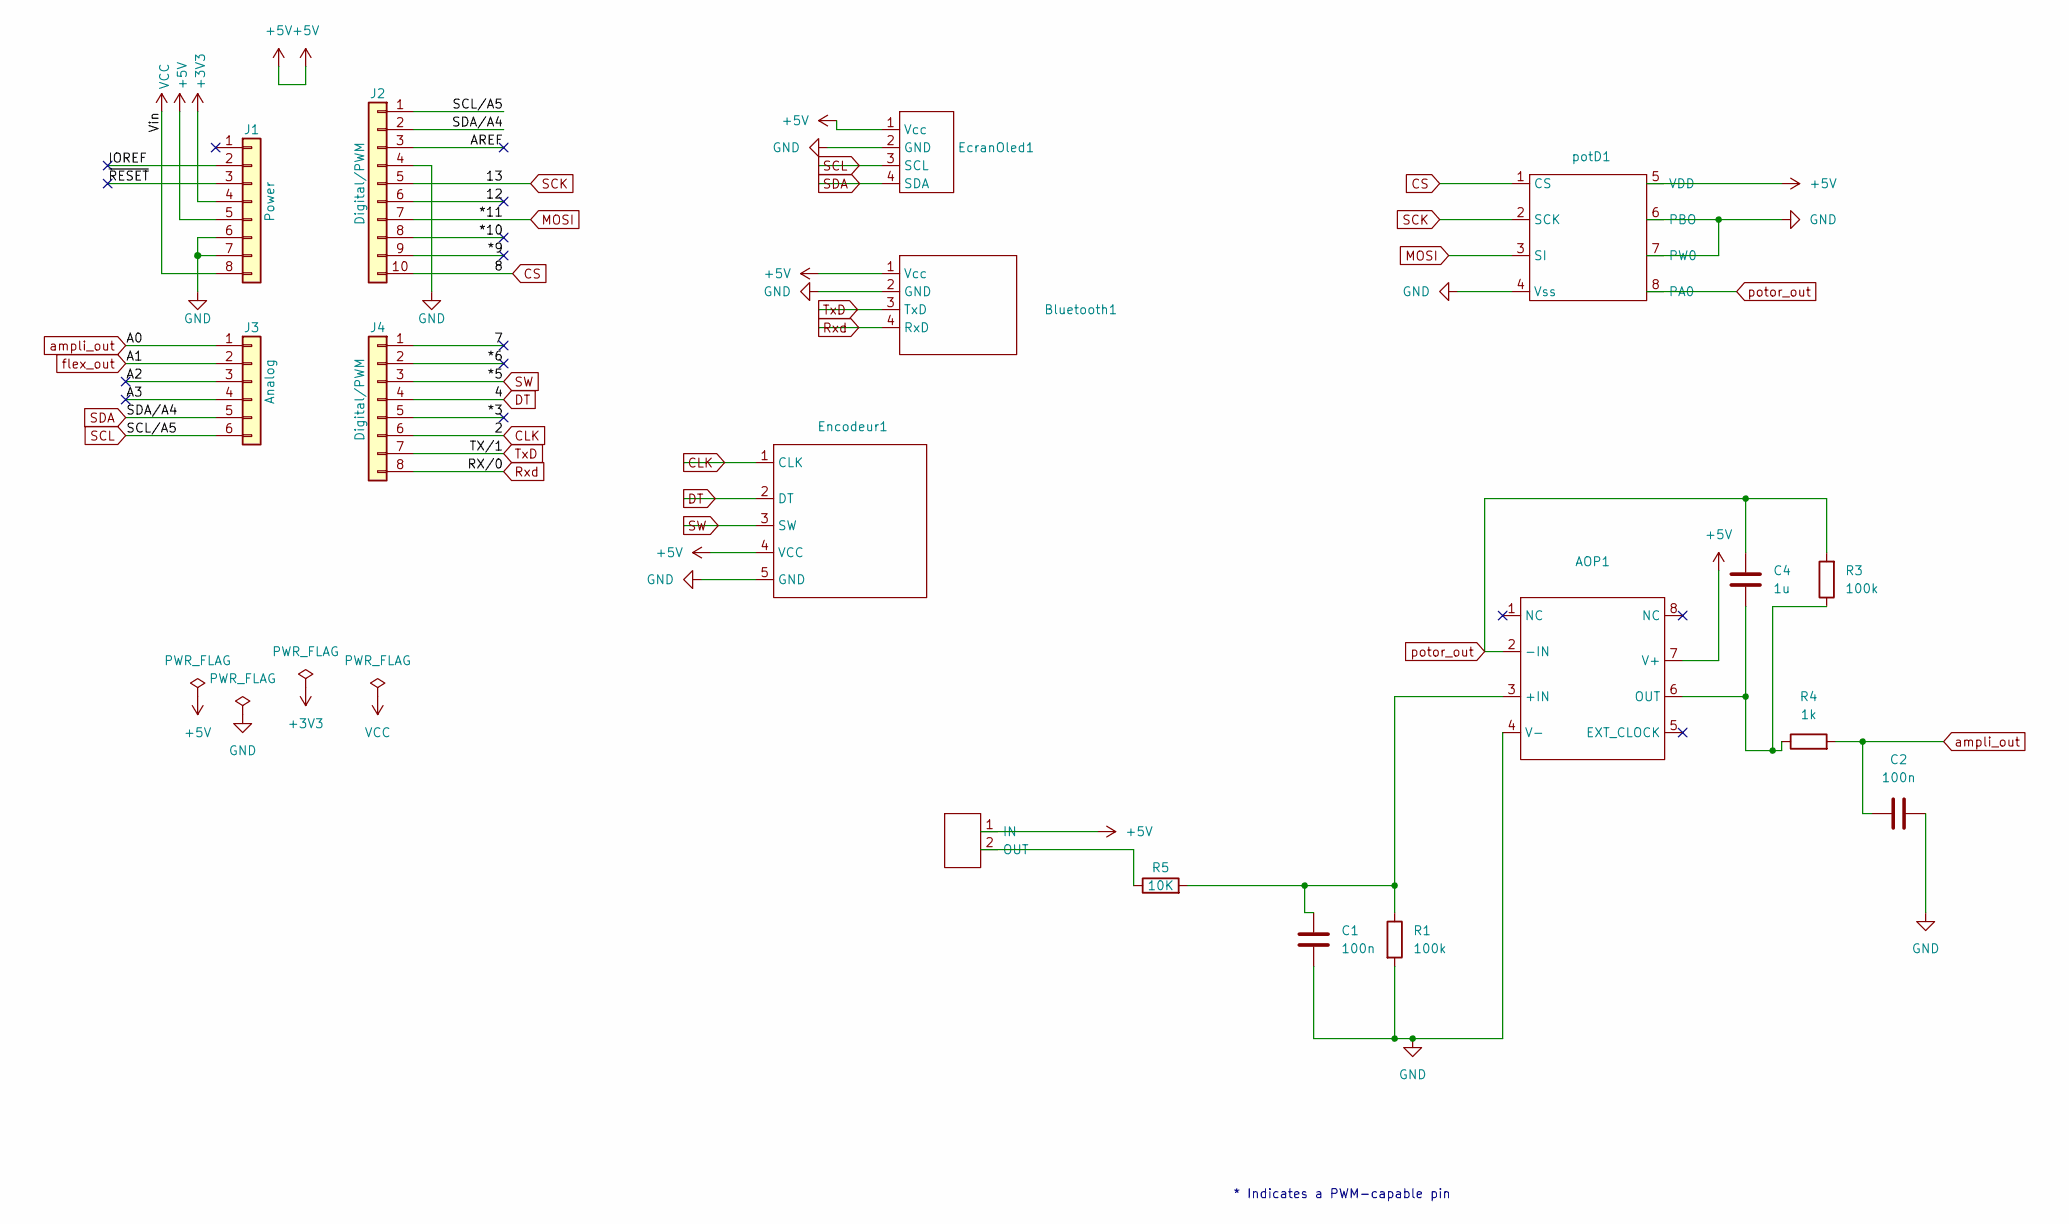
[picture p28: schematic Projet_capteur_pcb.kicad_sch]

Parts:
AOP1: AO
Bluetooth1: Empreinte_bluetooth
C1, C2: 100n; C_Disc_D7.5mm_W2.5mm_P5.00mm
C4: 1u; C_Rect_L7.2mm_W7.2mm_P5.00mm_FKS2_FKP2_MKS2_MKP2
EcranOled1: EcranOled
Encodeur1: ENCODEUR
J1: Power; PinSocket_1x08_P2.54mm_Vertical
J2: Digital/PWM; PinSocket_1x10_P2.54mm_Vertical
J3: Analog; PinSocket_1x06_P2.54mm_Vertical
J4: Digital/PWM; PinSocket_1x08_P2.54mm_Vertical
R1, R3: 100k; R_Axial_DIN0207_L6.3mm_D2.5mm_P10.16mm_Horizontal
R4: 1k; R_Axial_DIN0207_L6.3mm_D2.5mm_P10.16mm_Horizontal
R5: 10K; R_Axial_DIN0207_L6.3mm_D2.5mm_P10.16mm_Horizontal
capteur1: DIP-2_296_ELL
potD1: dig pot

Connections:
+3V3: J1.4
+5V: AOP1.7 (V+), Bluetooth1.1 (Vcc), EcranOled1.1 (Vcc), Encodeur1.4 (VCC), J1.5, capteur1.1 (IN), potD1.5 (VDD)
/7: J4.1
/12: J2.6
/*3: J4.5
/*6: J4.2
/*9: J2.9
/*10: J2.8
/A2: J3.3
/A3: J3.4
/AREF: J2.3
/IOREF: J1.2
/~RESET: J1.3
CLK: Encodeur1.1 (CLK), J4.6
CS: J2.10, potD1.1 (CS)
DT: Encodeur1.2 (DT), J4.4
GND: AOP1.4 (V-), Bluetooth1.2 (GND), C1.2, C2.2, EcranOled1.2 (GND), Encodeur1.5 (GND), J1.6, J1.7, J2.4, R1.2, potD1.4 (Vss), potD1.6 (PBO), potD1.7 (PW0)
MOSI: J2.7, potD1.3 (SI)
unnamed: AOP1.3 (+IN), C1.1, R1.1, R5.2
unnamed: AOP1.6 (OUT), C4.2, R3.1, R4.1
unnamed: R5.1, capteur1.2 (OUT)
Rxd: Bluetooth1.4 (RxD), J4.8
SCK: J2.5, potD1.2 (SCK)
SCL: EcranOled1.3 (SCL), J2.1, J3.6
SDA: EcranOled1.4 (SDA), J2.2, J3.5
SW: Encodeur1.3 (SW), J4.3
TxD: Bluetooth1.3 (TxD), J4.7
VCC: J1.8
ampli_out: C2.1, J3.1, R4.2
flex_out: J3.2
potor_out: AOP1.2 (-IN), C4.1, R3.2, potD1.8 (PA0)

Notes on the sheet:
* Indicates a PWM-capable pin

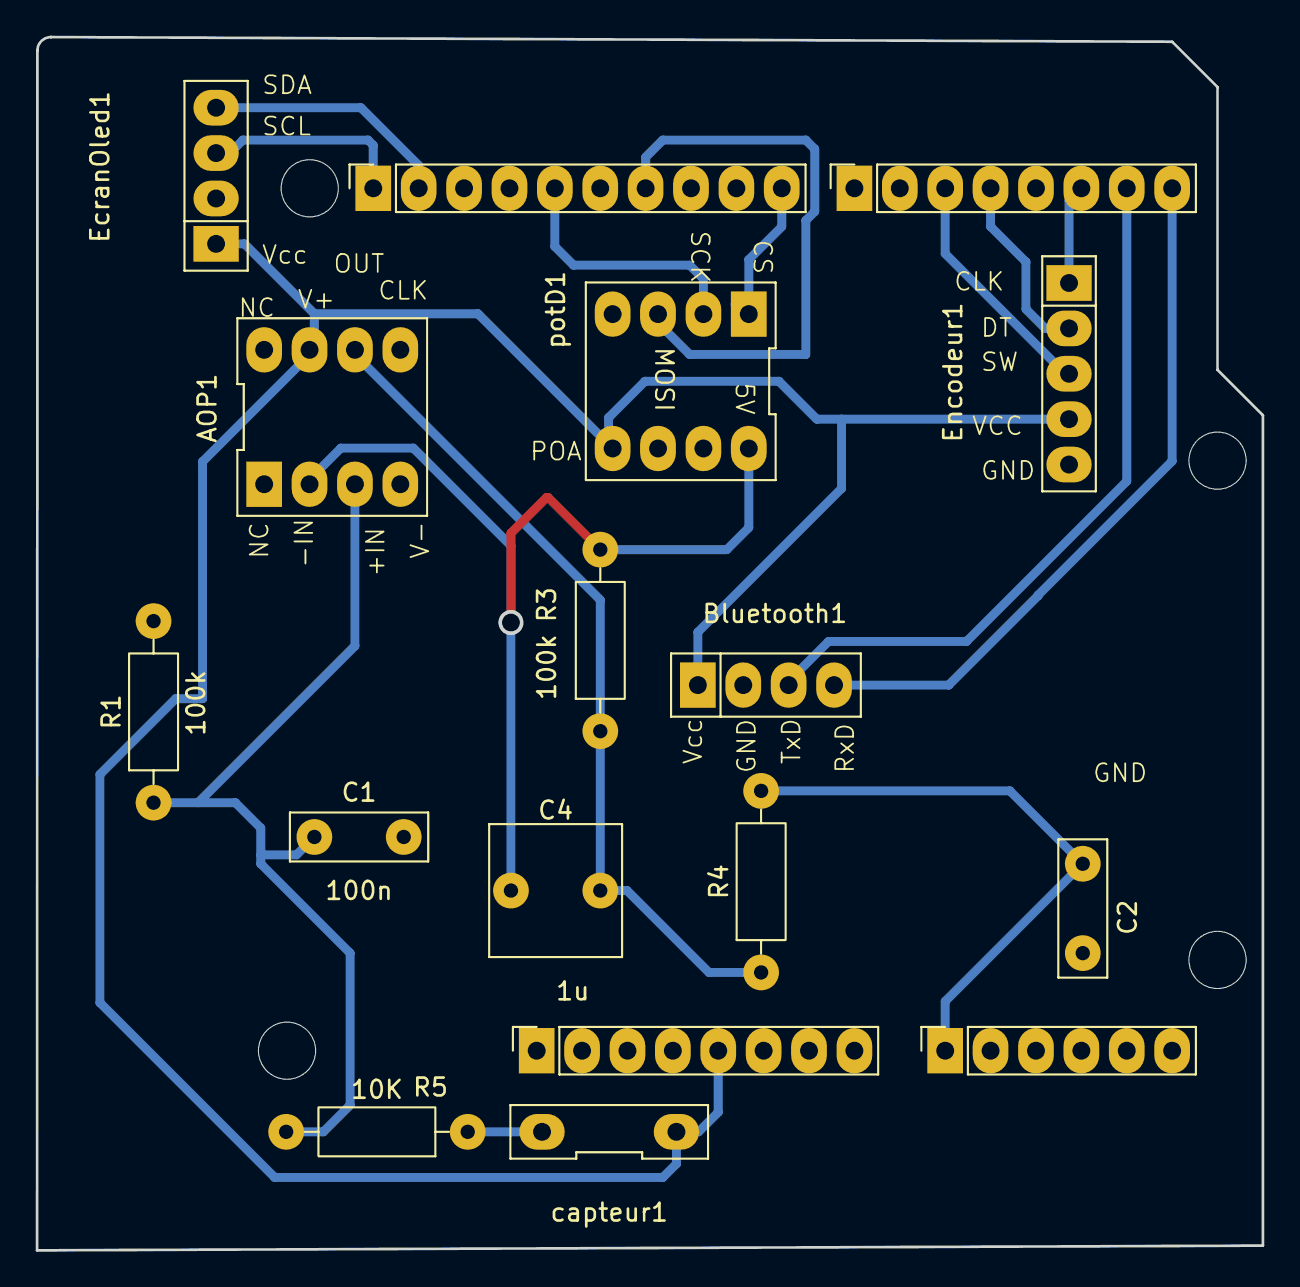
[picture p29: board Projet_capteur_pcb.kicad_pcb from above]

Board: 2 copper layers, 68.6 x 67.9 mm, 21 parts (0 on the bottom side), 17 nets.

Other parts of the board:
MH1, MH2, MH3, MH4: MountingHole_3.2mm

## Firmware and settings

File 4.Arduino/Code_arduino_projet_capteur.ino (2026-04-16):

//---------------------------------
//---BIBLIOTHEQUES ET CONSTANTES---
//---------------------------------

//---Bibliothèques---
#include <SPI.h>
#include <Wire.h>
#include <Adafruit_SSD1306.h>
#include <Adafruit_GFX.h>
#include <SoftwareSerial.h>


//--- Constantes capteur ---
const int Graphite_sensor = A0;  //Pin pour mesurer la tension aux bornes du capteur graphite
const int flex_sensor = A1;   //Pin pour mesurer la tension aux bornes du flex sensor

float VCC = 5.0;    //Tension d'alimentation

const float R_DIV = 47000.0;    //Résistance du pont diviseur de tension (capteur flex)
//Résistance de l'amplificateur transimpédance (cf. schéma LTSpice)
float R3 = 100000;
float R5 = 10000;
float R1 = 100000;

float Rf;   //Résistance globale du capteur graphite

float R_potentiometre;    //Résistance du potentiomètre digital
int pos = 128;    //Position du pas de départ du potentiomètre digital
int  maxPositions = 256;
const long rAB = 92500;   //Résistance du potentiomètre entre les points A et B 
const byte rWiper = 125;    //125 ohms pot wiper resistance

float Rflex_min;
float value_flex;


//---Communication bluetooth---
#define rxPin 9 //Broche rx
#define txPin 10 //Broche tx
#define baudrate 9600
SoftwareSerial mySerial(rxPin ,txPin); 

//--- Potentiomètre digital ---
#define MCP_NOP     0b00000000
#define MCP_WRITE   0b00010001
#define MCP_SHTDWN  0b00100001
const int ssMCPin = 8; 

//--- Écran OLED ---
#define OLED_WIDTH  128
#define OLED_HEIGHT 64
#define OLED_RESET  -1
#define adresseI2CecranOLED     0x3C
Adafruit_SSD1306 ecranOLED(OLED_WIDTH, OLED_HEIGHT, &Wire, OLED_RESET);

//--- Encodeur rotatoire---
int etat_bouton = 0;    //Pour lire l'état du bouton de l'encoder rotatoire
#define BUTTON_PIN  5
#define encoder0PinA  2  //CLK Output A Do not use other pin for clock as we are using interrupt
#define encoder0PinB  4  //DT Output B
#define Switch 5 // Switch connection if available
volatile int encoder0Pos = 1;

//--- Menu ---
int condition = 0;    //Pour gérer quel mode du menu utiliser (0=Tension, 1=Résistance, 2=Calibration, 3=Changement de capteur)
bool modeChoisi = false;  //True si on appuie pour valider
bool switchLastState = HIGH;
int x_graph = 0;

//---Changement de capteur---
bool cond_capteur = true; //True = capteur graphite et False = Flex sensor
char capt[30];


//------------------------------
//---DEFINITION DES FONCTIONS---
//------------------------------

//---Lecture tension---
float lecture_tension() {
  float Vadc;
  if (cond_capteur){ //Lecture de la tension pour le capteur graphite
    Vadc = analogRead(Graphite_sensor);
  }
  else{ //Lecture de la tension pour le flex sensor
    Vadc = analogRead(flex_sensor);
  }
  return (Vadc * VCC) / 1023.0;
}

//---Calcul de la résistance---
float calcul_resistance() {
  float tension = lecture_tension();
   if (cond_capteur){ //Pour le capteur graphite
    R_potentiometre = ((rAB * pos) / maxPositions ) + rWiper; //Résistance du potentiomètre
    Rf = ((1 + (R3 / R_potentiometre)) * (VCC / tension)) * R1 - R1 - R5;
    return Rf;
  }
  else{ //Pour le flex sensor
    float Rflex = R_DIV * (VCC / tension - 1.0); 
    return Rflex;
  }
}

//---Variables globales pour les mesures---
float tension = lecture_tension();
float resistance = calcul_resistance();

//---Changement de capteur---
void changement_capteur(){
  if (cond_capteur == true){
    strcpy(capt, "Capteur graphite");
  }
  else{
  
    strcpy(capt, "Flex sensor");
}
}

//---Ecriture dans le potentiomètre digital---
void ecriture_potentiometre(uint8_t cmd, uint8_t data, uint8_t ssPin) {
  SPI.beginTransaction(SPISettings(14000000, MSBFIRST, SPI_MODE0));
  digitalWrite(ssPin, LOW);
  SPI.transfer(cmd);
  SPI.transfer(data);
  digitalWrite(ssPin, HIGH);
  SPI.endTransaction();
}

//---Calibration---
void calibration() {
  float tension_cible = 2.5;
  float diff1, diff2;

  diff1 = abs(tension - tension_cible);
  do {
    //Affichage sur l'écran de l'ordinateur des paramètres de calibration
    Serial.println(F("Tension mesurée"));
    Serial.println(tension);
    Serial.println(F("Position du potentiomètre"));
    Serial.println(pos);
    ecriture_potentiometre(MCP_WRITE, pos, ssMCPin);
    delay(200);
    tension = lecture_tension();
    diff2 = abs(tension - tension_cible);

    if (diff2 > diff1) {
      if (pos == 255) pos = 1;
      else pos++;
    } else {
      if (pos == 0) pos = 255;
      else pos--;
    }
    diff1 = abs(tension - tension_cible);

  } while ((tension < 2.4 || tension > 2.6));
  //On calcule la différence entre la tension mesurée et la tension initiale avant er après
  //le changement de position. On les compare et on incrémente le pas en fonction.

  //Affichage sur l'écran de l'oridnateur des paramètres retenus
  Serial.print(F("Tension calibrée: "));
  Serial.println(tension);
  resistance = calcul_resistance();
  Serial.print(F("Pot calibré position: "));
  Serial.println(pos);
  Serial.print(F("Resistance au repos: "));
  Serial.println(resistance);
}

//_______________________________
//---Ecriture sur l'écran OLED---

//---Message de bienvenue---
void affichage_initialisation() {
  ecranOLED.clearDisplay();
  ecranOLED.setCursor(0,0);
  ecranOLED.setTextSize(1);
  ecranOLED.println(F("Bienvenue!"));
  ecranOLED.display();
}

//---Message de calibration---
void affichage_calibration() {
  if (cond_capteur){
  ecranOLED.clearDisplay();
  ecranOLED.setCursor(0,0);
  ecranOLED.setTextSize(1);
  ecranOLED.println(F("Calibration en cours..."));
  ecranOLED.display();
  calibration();
  ecranOLED.clearDisplay();
  ecranOLED.setCursor(0,0);
  ecranOLED.println(F("Calibration terminee!"));
  ecranOLED.println();
  ecranOLED.println(F("Tension calibree: "));
  ecranOLED.print(tension);
  ecranOLED.println(F("Position potentiometre: "));
  ecranOLED.print(pos);
  ecranOLED.println(F("Resistance au repos: "));
  ecranOLED.print(Rf);
    
  }
  else{
    ecranOLED.clearDisplay();
    ecranOLED.setCursor(0,0);
    ecranOLED.setTextSize(1);
    ecranOLED.println(F("La calibration n'est pas necessaire pour le flex sensor."));
  }
  ecranOLED.display();
}

//---Affichage de la tension---
void affichage_ecran_tension() {
  ecranOLED.clearDisplay();
  ecranOLED.setTextSize(1);
  ecranOLED.setCursor(0,0);
  ecranOLED.println(F("Tension capteur:"));
  ecranOLED.println();
  ecranOLED.println(tension);
  ecranOLED.println();
  ecranOLED.println("V");

  //Fonction pour afficher en bas à droite de l'écran le capteur utilisé
  if (cond_capteur == true){
   ecranOLED.setCursor(32, 56);
   ecranOLED.println(F("Capteur graphite"));
  }
  else{
    ecranOLED.setCursor(62, 56);
    ecranOLED.println(F("Flex sensor"));
  }
  ecranOLED.display();
}

//---Affichage de la résistance---
void affichage_ecran_resistance() {
  ecranOLED.clearDisplay();
  ecranOLED.setTextSize(1);
  ecranOLED.setCursor(0,0);
  ecranOLED.println(F("Resistance capteur:"));
  ecranOLED.println();
  ecranOLED.println(resistance);
  ecranOLED.println();
  ecranOLED.println("ohm");

  //Fonction pour afficher en bas à droite de l'écran le capteur utilisé
  if (cond_capteur == true){
   ecranOLED.setCursor(32, 56);
   ecranOLED.println(F("Capteur graphite"));
  }
  else{
    ecranOLED.setCursor(62, 56);
    ecranOLED.println(F("Flex sensor"));
  }
  ecranOLED.display();
}

//---Affichage du choix du capteur---
void affichage_capteur() {
  changement_capteur();
  ecranOLED.clearDisplay();
  ecranOLED.setTextSize(1);
  ecranOLED.setCursor(0,0);
  ecranOLED.println(F("Capteur:"));
  ecranOLED.println();
  ecranOLED.println(capt);
  ecranOLED.display();
}

//--- Affichage du menu---
void affichage_menu() {
  ecranOLED.clearDisplay();
  ecranOLED.setTextSize(1);
  ecranOLED.setCursor(0,0);
  ecranOLED.println(F("Choix du mode:"));
  ecranOLED.println();

  if(condition == 0) ecranOLED.println(F("> Tension"));
  else ecranOLED.println(F("  Tension"));

  if(condition == 1) ecranOLED.println(F("> Resistance"));
  else ecranOLED.println(F("  Resistance"));

  if(condition == 2) ecranOLED.println(F("> Calibration"));
  else ecranOLED.println(F("  Calibration"));

  if(condition == 3) ecranOLED.println(F("> Capteur"));
  else ecranOLED.println(F("  Capteur"));

  //Fonction pour afficher en bas à droite de l'écran le capteur utilisé
  if (cond_capteur == true){
   ecranOLED.setCursor(32, 56);
   ecranOLED.println(F("Capteur graphite"));
  }
  else{
    ecranOLED.setCursor(62, 56);
    ecranOLED.println(F("Flex sensor"));
  }
  ecranOLED.display();
}

//---Bouton de l'encodeur---
void checkButton() {
  bool switchState = digitalRead(BUTTON_PIN);

  if (switchState == LOW && switchLastState == HIGH) {
    delay(50); 

    if (digitalRead(BUTTON_PIN) == LOW) {
      if (modeChoisi == false) {
        modeChoisi = true;
      } else {
        modeChoisi = false;
        affichage_menu();
      }
    }
  }
  switchLastState = switchState;
}

//---Communication bluetooth---
void setup_bluetooth(){
  pinMode(rxPin,INPUT);
  pinMode(txPin,OUTPUT);
    
  mySerial.begin(baudrate);
}

//---Boucle de communication bluetooth---
void loop_bluetooth(float variable){
  if (isinf(variable)) {
  mySerial.print("inf"); // Envoie une valeur plafond au lieu de "inf"
  } else {
  mySerial.print(variable);
  }
  mySerial.print(",");
  mySerial.print(condition);
  mySerial.print(",");
  mySerial.print(cond_capteur ? 1 : 0); //envoie 1 si true et 0 si false
  mySerial.print("\n");
}

//---Encodeur rotatoire---
void encodeur() {
  if (modeChoisi == true) {

    if (condition == 0) { //Mesure de tension
      do{
      tension = lecture_tension();
      affichage_ecran_tension();
      loop_bluetooth(tension);
      delay(50);
      checkButton();
      position_encodeur(); 
      if (modeChoisi == false) break;
      }while(condition == 0);
      
    }
    else if (condition == 1) { //Mesure de résistance
      do{
      resistance = calcul_resistance();
      affichage_ecran_resistance();
      loop_bluetooth(resistance);
      delay(50);
      checkButton();
      position_encodeur(); 
      if (modeChoisi == false) break;
      }while(condition == 1);
    }
    else if (condition == 2) { //Calibration
      affichage_calibration();
      do{
      checkButton();
      if (modeChoisi == false) break;
      }while(condition == 2);
    }
    else if (condition == 3){ //Changement de capteur
      if (cond_capteur==true){
        cond_capteur = false;
      }
      else {
        cond_capteur = true;
      }
      do{
      affichage_capteur();
      checkButton();
      if (modeChoisi == false) break;
      }while(condition == 3);
    }
}
}

//---Setup de l'encodeur rotatoire---
void encodeur_setup(){
  pinMode(encoder0PinA, INPUT); 
  digitalWrite(encoder0PinA, HIGH);       

  pinMode(encoder0PinB, INPUT); 
  digitalWrite(encoder0PinB, HIGH);       

  attachInterrupt(0, do_encodeur, RISING); 
}

//---Incrémentation du pas de l'encodeur---
void do_encodeur() {
  if (digitalRead(encoder0PinA)==HIGH && digitalRead(encoder0PinB)==HIGH) {
    encoder0Pos++;
  } else if (digitalRead(encoder0PinA)==HIGH && digitalRead(encoder0PinB)==LOW) {
    encoder0Pos--;
  }

  //Si on a fait un tour complet, le compteur repart à 0
  if (encoder0Pos == 30){
    encoder0Pos = 0;
  }
  if (encoder0Pos == -1){
    encoder0Pos = 30;
  }
}

//---lecture la position de l'encodeur---
void position_encodeur(){
  if ((encoder0Pos<=7 && 0 <encoder0Pos)){
    condition = 0; //Tension
  }
  else if ((encoder0Pos<=14 && 7<encoder0Pos)){
    condition = 1; //Résistance
  }
  
  else if ((encoder0Pos<=21 && 14<encoder0Pos)){
    condition = 2; //Calibration
  }
   else if ((encoder0Pos<=30 && 21<encoder0Pos)){
    condition = 3; //Capteur
  }
}

//---Setup---
void setup() {
  //Initialisation du potentiomètre
  pinMode(ssMCPin, OUTPUT); 
  digitalWrite(ssMCPin, HIGH);
  SPI.begin(); 

  //Initialisation de l'encodeur
  encodeur_setup();

  //Baud rate
  Serial.begin(9600);

  //Initialisation de l'écran OLED
  if(!ecranOLED.begin(SSD1306_SWITCHCAPVCC, adresseI2CecranOLED))
    while(1);  
  ecranOLED.setTextColor(SSD1306_WHITE);
  ecranOLED.setTextWrap(true);
  affichage_initialisation();
  delay(2000);

  //Calibration du capteur graphite
  affichage_calibration();

  //Initialisation du bluetooth
  setup_bluetooth();
  pinMode(BUTTON_PIN, INPUT_PULLUP);

  affichage_menu();
  Serial.println("Calibration terminée");
}

// --- Loop ---
void loop() {
  //Lecture de l'état du bouton de l'encodeur rotatoire
  checkButton();
  
  int ancienneCondition = condition;
  position_encodeur();

  //Affichage du menu
  if (condition != ancienneCondition) {
    affichage_menu();
  }

  encodeur();
  delay(100);
}

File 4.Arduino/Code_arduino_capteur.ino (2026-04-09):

#include <SPI.h>
#include <Adafruit_SSD1306.h>
#include <Wire.h>

//---Constantes---
const int flexPin = A0; //Pin de sortie de l'amplificateur
float VCC = 5.0;
const float R_DIV = 47000.0; //Résistance pour le pont diviseur de tension
float Rflex_min; //Résistance au repos calibrée

//---Constantes pour le potentiomètre digital---
#define MCP_NOP 0b00000000
#define MCP_WRITE 0b00010001
#define MCP_SHTDWN 0b00100001
const int ssMCPin = 8; 

//---Initialisation de l'écran OLED---
#define nombreDePixelsEnLargeur 128         // Taille de l'écran OLED, en pixel, au niveau de sa largeur
#define nombreDePixelsEnHauteur 64          // Taille de l'écran OLED, en pixel, au niveau de sa hauteur
#define brocheResetOLED         -1          // Reset de l'OLED partagé avec l'Arduino (d'où la valeur à -1, et non un numéro de pin)
#define adresseI2CecranOLED     0x3C
Adafruit_SSD1306 ecranOLED(nombreDePixelsEnLargeur, nombreDePixelsEnHauteur, &Wire, brocheResetOLED);

//---Initialisation de l'encodeur rotatoire---
#define encoder0PinA  2  //CLK Output A Do not use other pin for clock as we are using interrupt
#define encoder0PinB  4  //DT Output B
#define Switch 5 // Switch connection if available
volatile unsigned int encoder0Pos = 0;


//Fonction qui lit la tension en sortie de l'amplificateur 
float  lecture_tension(){
  float Vadc = analogRead(flexPin);
  return (Vadc*VCC)/ 1023.0;
}

//Fonction qui lit la résistance du capteur à l'aide d'un pont diviseur de tension
float calculateFlexResistance() {
  float Vadc = lecture_tension();
  return R_DIV * (VCC / Vadc - 1.0);
}

void ecriture_potentiometre(uint8_t cmd, uint8_t data, uint8_t ssPin) 
{
  SPI.beginTransaction(SPISettings(14000000, MSBFIRST, SPI_MODE0)); 
  digitalWrite(ssPin, LOW); 
  SPI.transfer(cmd);        
  SPI.transfer(data);       
  digitalWrite(ssPin, HIGH);
  SPI.endTransaction();
}

void calibration(){
  float tension_AO = lecture_tension();
  float tension_cible = 2.5;
  float tolerance = 0.05;
  int pos = 128;
  float diff1;
  float diff2;

  diff1 = abs((tension_AO-tension_cible));

  do{
      Serial.println (tension_AO);
      Serial.println (pos);
      ecriture_potentiometre(MCP_WRITE, pos, ssMCPin);
      delay(100);
      tension_AO = lecture_tension();
      diff2 = abs((tension_AO-tension_cible));

      if (diff2 > diff1) {
        if (pos == 255){
          pos = 1;
        }
        else{
        pos +=1;
        }
      }
      else
      {
        if (pos == 0){
          pos = 254;
        }
        else{
        pos -=1;
        }
      }
      diff1 = abs((tension_AO-tension_cible));

    } while ((tension_AO < 2.4 || tension_AO > 2.6));

  Serial.println ("CALIBRATION: La tension aux bornes de l'amplificateur vaut ");
  Serial.println (tension_AO);
  Rflex_min = calculateFlexResistance();
  Serial.print("Pot calibré pour 0° à la position : ");
  Serial.println(pos);
  Serial.print("Resistance au repos : ");
  Serial.println(Rflex_min);
}

void affichage_ecran(){
  float tension;

  ecranOLED.clearDisplay();
  
  ecranOLED.setTextSize(2); 
  ecranOLED.setCursor(0, 0);
  ecranOLED.println("Tension capteur:"); 
  ecranOLED.println();

  ecranOLED.setTextSize(2); 
  tension=lecture_tension();
  ecranOLED.println(tension);

  ecranOLED.display();
}

void doEncoder() {

  if (digitalRead(encoder0PinB)==HIGH) {
    if (encoder0Pos = 30){
      encoder0Pos = 0;
    }
    else{
    encoder0Pos++;
    }
  } else {
    if (encoder0Pos =0){
      encoder0Pos = 30;
    }
    else{
    encoder0Pos--;
    }
  }
}

void setup() {
  //---Initialisation du potentiomètre---
  pinMode (ssMCPin, OUTPUT); 
  digitalWrite(ssMCPin, HIGH);
  SPI.begin(); 

  //---Baud rate---
  Serial.begin(9600);

  //---Initialisation de l'écran OLED
  if(!ecranOLED.begin(SSD1306_SWITCHCAPVCC, adresseI2CecranOLED)) {
    Serial.println(F("Échec de l'initialisation de l'écran OLED"));
    for(;;);
    }
  ecranOLED.setTextColor(SSD1306_WHITE);
  ecranOLED.setTextWrap(true);

  //---Initialisation de l'encodeur rotatoire---
  pinMode(encoder0PinA, INPUT); 
  digitalWrite(encoder0PinA, HIGH);       
  pinMode(encoder0PinB, INPUT); 
  digitalWrite(encoder0PinB, HIGH);     
  attachInterrupt(0, doEncoder, RISING); 

  //---Calibration de la tension aux bornes du capteur
  //calibration();
}


void loop() {
  float tension;
  tension=lecture_tension();
  Serial.println(tension);
  affichage_ecran();

  Serial.print("Position:");
  Serial.println (encoder0Pos, DEC);

  delay(500);
}

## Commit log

2026-02-24 projet capteur dans le main
    [Projet_capteur_pcb.kicad_pcb, Projet_capteur_pcb.kicad_sch]
2026-02-24 3D + placement
    [OLED 128x64.STP, Projet_capteur_pcb.kicad_pcb, Projet_capteur_pcb.kicad_sch]
2026-02-28 routageV1 modif
    [Projet_capteur_pcb.kicad_pcb]
2026-04-09 Update README with KiCad PCB design information
    Added details about the PCB design process using KiCad.
2026-04-09 Revise component list and add PCB images in README
    Updated the list of components used for the transimpedance amplifier and added images of the PCB.
2026-04-09 Enhance Kicad section with PCB design steps
    Updated the Kicad section to provide detailed steps for PCB design, including schematic entry, routing, and 3D visualization.
2026-04-12 Enhance README with images and Arduino details
    Updated images and improved Arduino section for clarity.
2026-04-12 Refactor Arduino code for sensor calibration and display
2026-04-16 datasheet+banc de test
    [bancs-de-test.xlsx]
2026-05-14 bon jusquà la partie 3
2026-05-14 Fix image tag formatting for PCB visualization
    Updated the image tag for PCB visualization in README.
2026-05-14 Enhance README with centered routing visualization text
    Added a centered paragraph for routing visualization in KiCad.
2026-05-14 Modify PCB routing visualization caption
    Updated the caption for the PCB routing visualization to use emphasis formatting.
2026-05-14 Update sensor question formatting in README
2026-05-14 Update README with PCB fabrication details and images
    Removed unnecessary table and added image with caption for PCB fabrication section.
2026-05-14 Update README with test results and images
    Added images and results for resistance measurements based on mechanical deformation.
